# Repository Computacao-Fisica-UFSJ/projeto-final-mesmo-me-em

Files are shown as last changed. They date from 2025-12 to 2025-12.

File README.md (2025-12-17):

# Documentação Arduino - Gato Comedor de Moedas

DEPARTAMENTO DE CIÊNCIA DA COMPUTAÇÃO
BACHARELADO EM CIÊNCIA DA COMPUTAÇÃO

**Computação Física com Arduino**
Prof. Milene Barbosa Carvalho

**Autores:**

* Eduardo Gomes Martins
* Marina Rihs Matos Wang

---

## 1. Introdução

Este projeto consiste em criar um gato que engole moedas, com um contador que mostra o quanto de dinheiro o gato "engoliu". O gato foi modelado utilizando biscuit, o sistema para movimentação do gato e contagem das moedas foi feita com peças de arduino e uma régua impressa na impressora 3D para separar as moedas, e toda a estrutura foi construída com papelão.

A inspiração para a realização deste trabalho veio inicialmente do brinquedo "Stealing Coin Cat Bank" feito com um gatinho que puxa a a moeda para dentro da caixa sempre que a moeda é colocada em uma posição espeçífica. Por apresentar um mecanismo um pouco complexo para o arduino, nos inspiramos no brinquedo do "Cofre Devora Moedas", que, ao invés de puxar a moeda, ele simplesmente come, o que deixa o mecanismo mais simples.

---

## 2. Materiais

### 1. Arduino MEGA 2560

<div align="center">
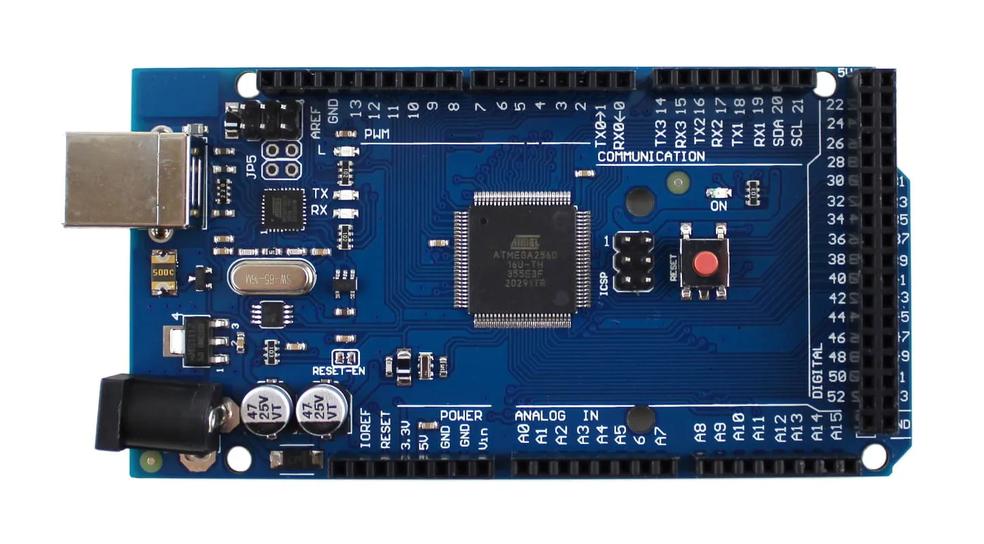
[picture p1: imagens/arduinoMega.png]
  
</div>

### 2. 2 x Breadboard - Full-Size

<div align="center">
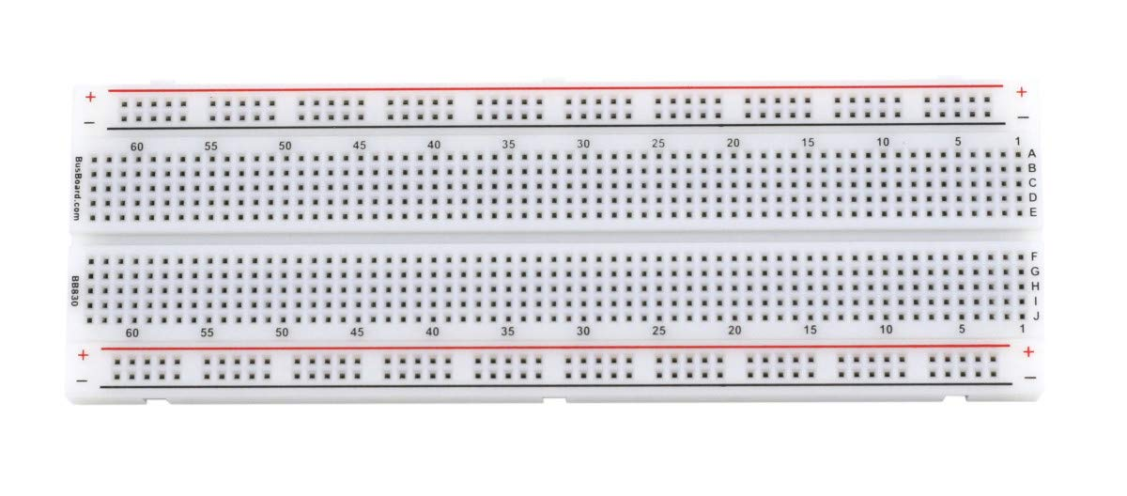
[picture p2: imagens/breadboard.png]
  
</div>

### 3. Jump Wires

<div align="center">
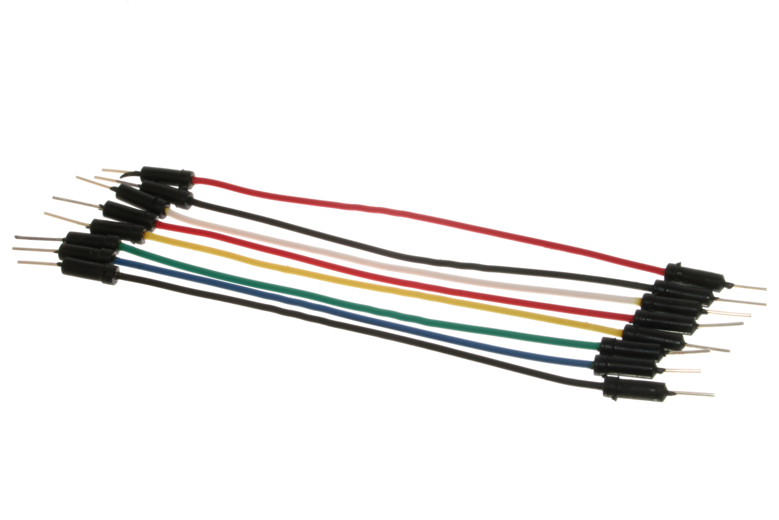
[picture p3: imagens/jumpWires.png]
  
</div>

### 4. Jump Wires Male to Female

<div align="center">
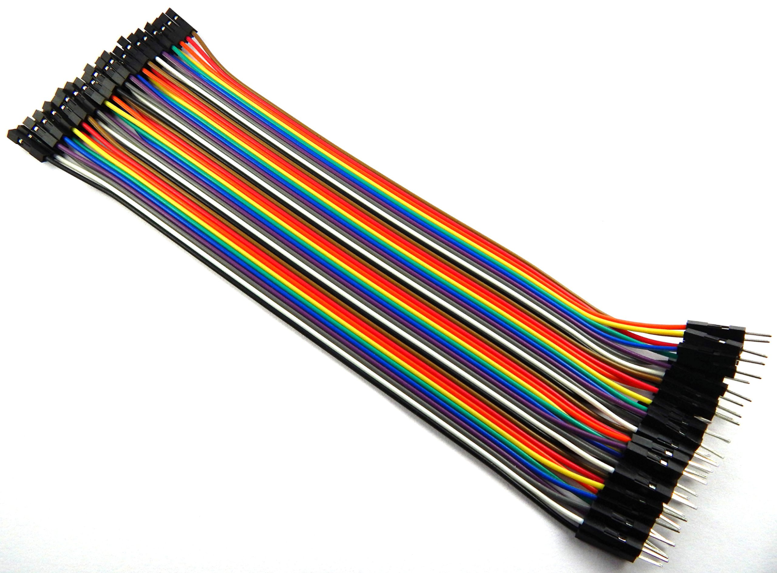
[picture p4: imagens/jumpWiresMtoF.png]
  
</div>

### 5. Jump Wires Female to Female

<div align="center">
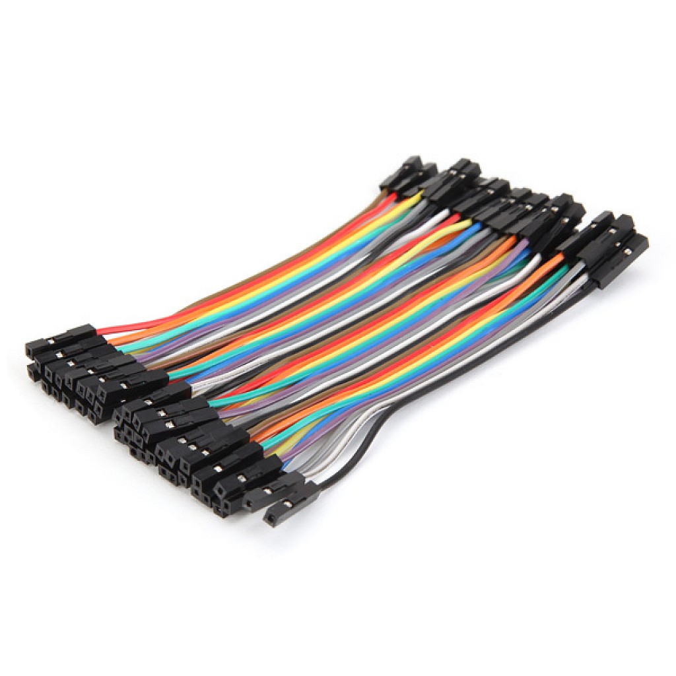
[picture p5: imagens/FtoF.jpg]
  
</div>

### 6. 7 x Sensor Infra Vermelho IR Emissor + Receptor

<div align="center">
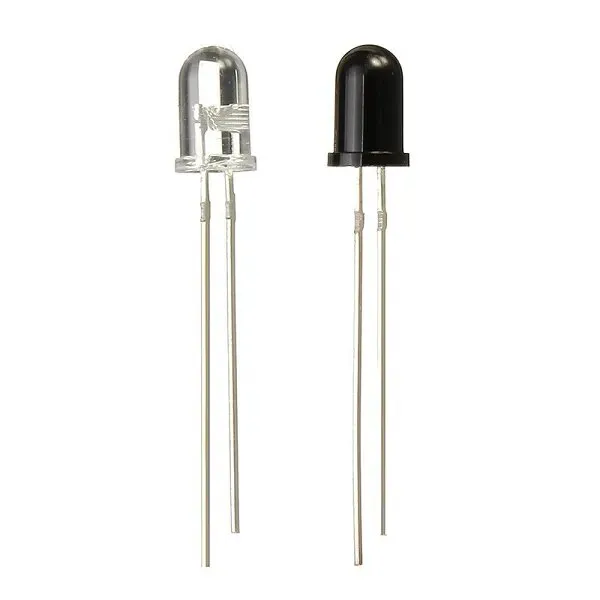
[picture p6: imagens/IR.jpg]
  
</div>

### 7. 7 x Resistor 10k ohm

<div align="center">
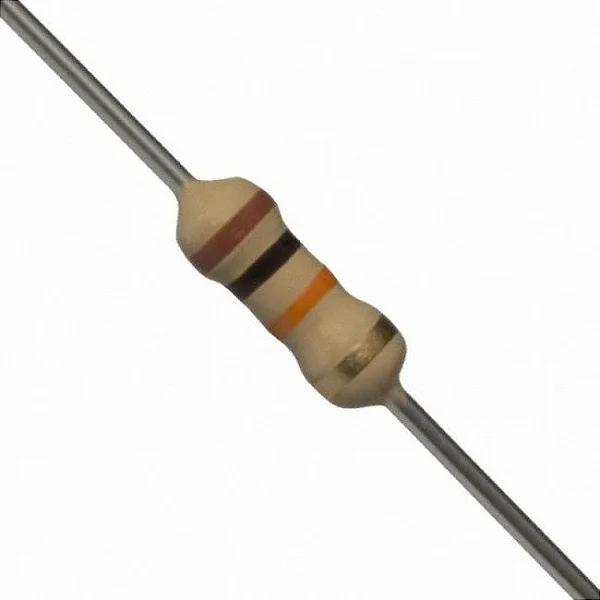
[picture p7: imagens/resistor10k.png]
  
</div>

### 8. 7 x Resistor 300 ohm

<div align="center">
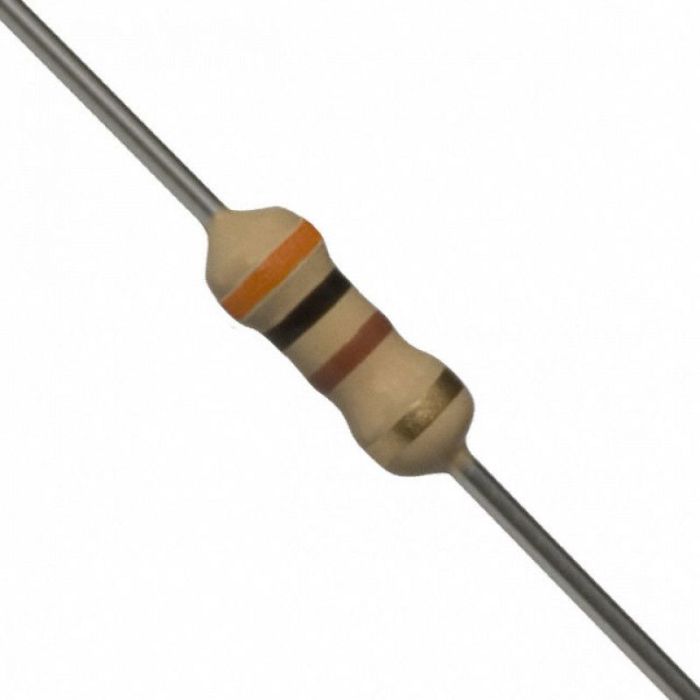
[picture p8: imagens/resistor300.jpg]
  
</div>

### 9. Limit Switch

<div align="center">
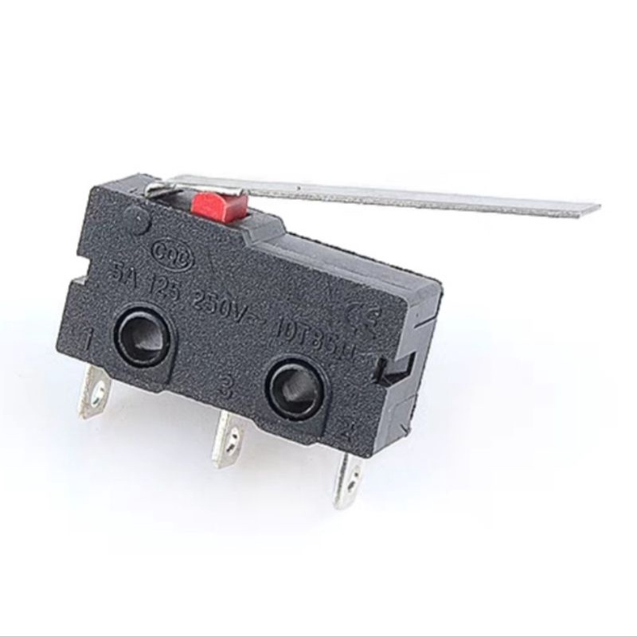
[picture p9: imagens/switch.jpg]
  
</div>

### 10. Grove-LCD RGB Backlight V2.0

<div align="center">
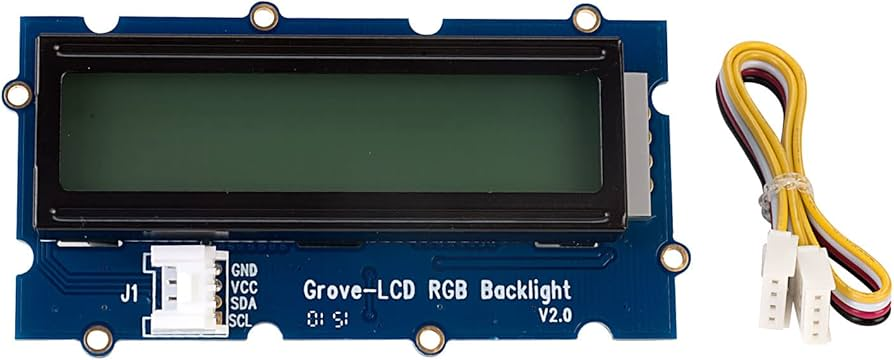
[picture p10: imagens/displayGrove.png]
  
</div>

---

## 3. Diagrama da Montagem (Fritzing)

<div align="center">
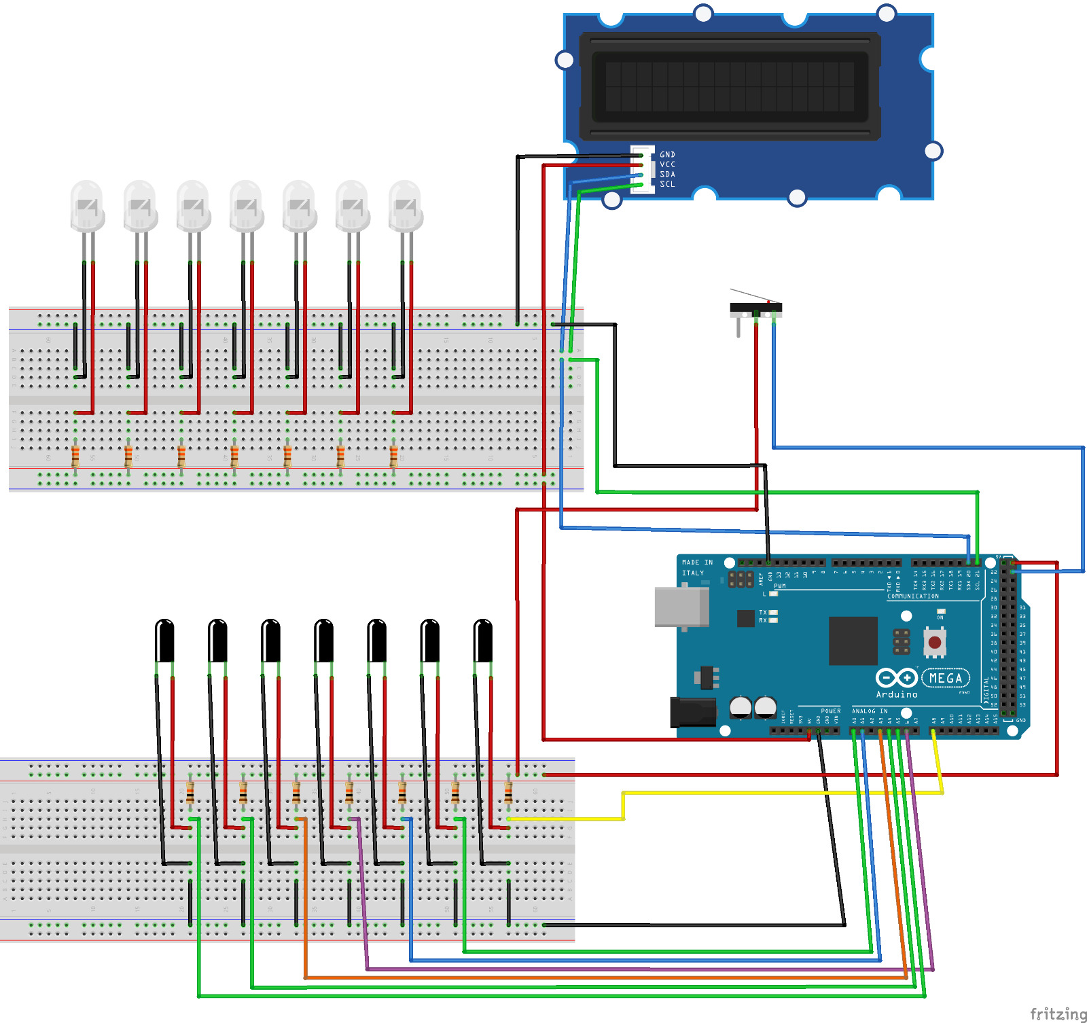
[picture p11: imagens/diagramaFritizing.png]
  
</div>

---

## 4. Explicação Textual do Diagrama

O circuito é dividido em três partes principais:

### 1. Switch
* O switch seria utilizado futuramente para ativar o mecanismo do gato, por  agora apenas libera uma mensagem.
* Ele é conectado no ground e ao pino 23, utilizando INPUT_PULLUP para fazer a leitura.

### 2. Sensores Infra Vermelho IR Emissor + Receptor
* Os sensores são utilizados para contabilizar as moedas, dependendo qual sensor teve seu valor modificado, identificamos qual o valor da moeda.
* Cada receptor está ligado a um pino de entrada analógica: A0, A1, A3, A4, A5, A6 e A8 sendo alimentado utilizando o resistor de 10k para limitar a corrente e evitar danos.
* Cada emissor está sendo alimentado utilizando o resistor de 330Ω para limitar a corrente e evitar danos.

### 3. Display LCD RGB
* Exibe o dinheiro total que passou pelo gato.
* Comunicação I2C pelos pinos 20 (SDA) e 21 (SCL).

---

## 5. Fotos/Vídeos do Projeto

* `Link do drive:` [https://drive.google.com/drive/folders/1Pybfmc_FEBHTFAq_Zw0lyVmJ8qzrmmvx](https://drive.google.com/drive/folders/1Pybfmc_FEBHTFAq_Zw0lyVmJ8qzrmmvx)

---

## 6. Problemas encontrados no Processo de Montagem

**a) Informações sobre componentes**

* Houve uma dificuldade para encontrar uma informações sobre como os sensores IR separados funcionavam no arduino e quais resistores são utilizados.
* Assim como os sensores IR, houve dificuldade em achar informações sobre o limit switch, em específico como funcionva sua alimentação de energia.

**b) Montagem do projeto**

* A régua que separa as moedas estava travando as moedas em pontos específicos, a solução foi ajeitar os buracos da régua com um pedaço de tecido para diminuir o diâmetro.
* Outro problema foi ajustar a inclinação da régua e o jeito com que a moeda cai sobre a régua.
* A mecânica do gato não funcionou como o esperado, ajustar o servo motor para movimentar a boca e os braços acabou ficando para a próxima atualização.
* Houve dificuldade em alinhar os infravermelhos em cada posição da régua, com um pouco de paciência, funcionou.

---

## 7. Referências

* Modelo 3D da régua separadora de moedas: [https://www.printables.com/model/53280-improved-auto-coin-sorter-v75-coin-roll-classic-ve/files](https://www.printables.com/model/53280-improved-auto-coin-sorter-v75-coin-roll-classic-ve/files)
* Datasheets dos componentes (LED, resistores, buzzer, botões, Arduino Uno).
* Documentação do LCD Grove RGB: [https://wiki.seeedstudio.com/Grove-LCD_RGB_Backlight/](https://wiki.seeedstudio.com/Grove-LCD_RGB_Backlight/)
* Documentação oficial do Arduino: [https://docs.arduino.cc/](https://docs.arduino.cc/)

---

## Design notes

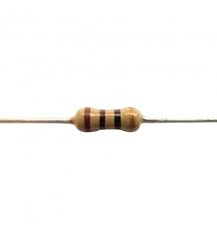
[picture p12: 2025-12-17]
imagens/resistor10.png

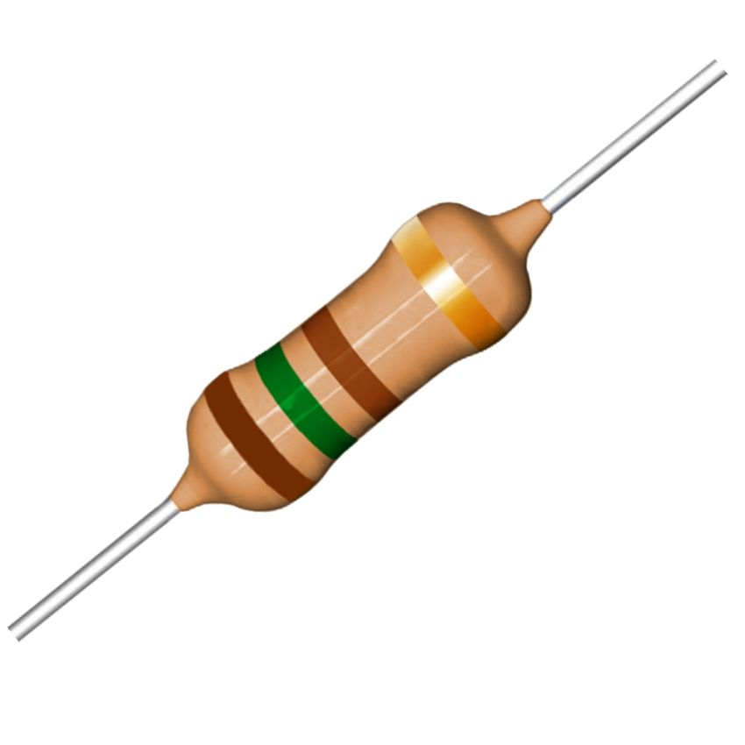
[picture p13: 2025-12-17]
imagens/resistor150.png

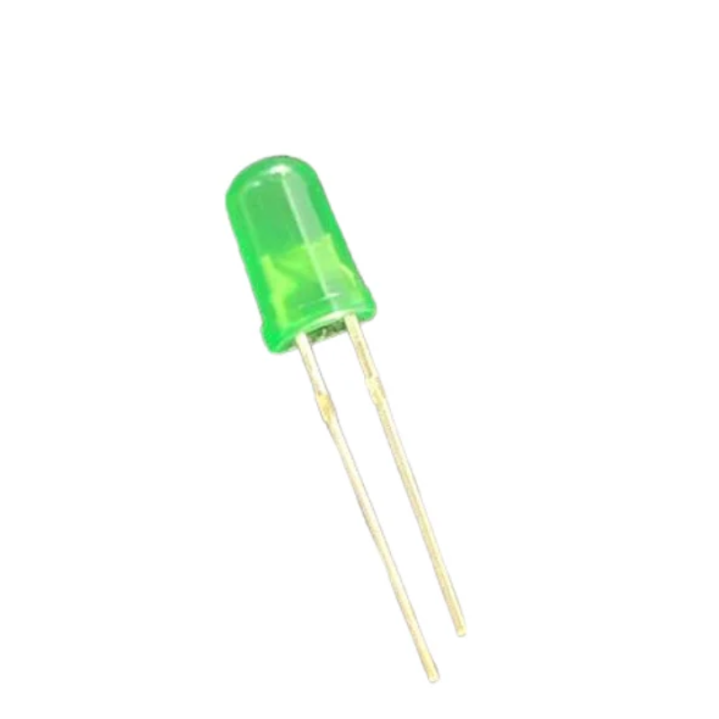
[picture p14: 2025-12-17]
imagens/ledVerde.png

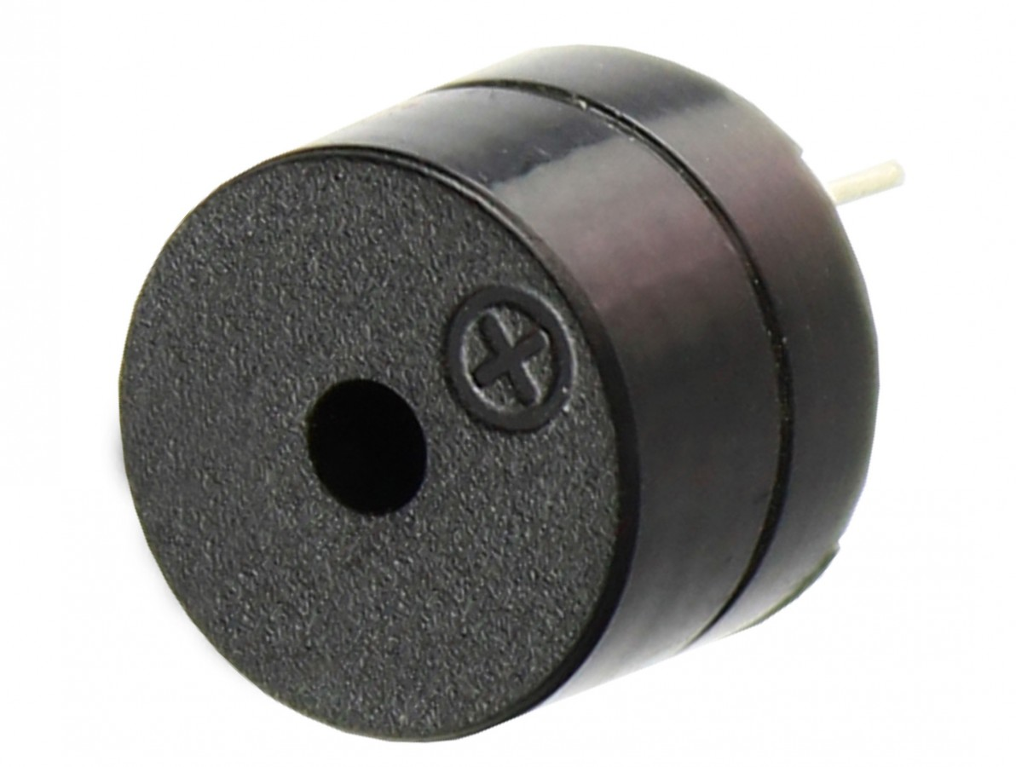
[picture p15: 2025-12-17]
imagens/buzzer.png

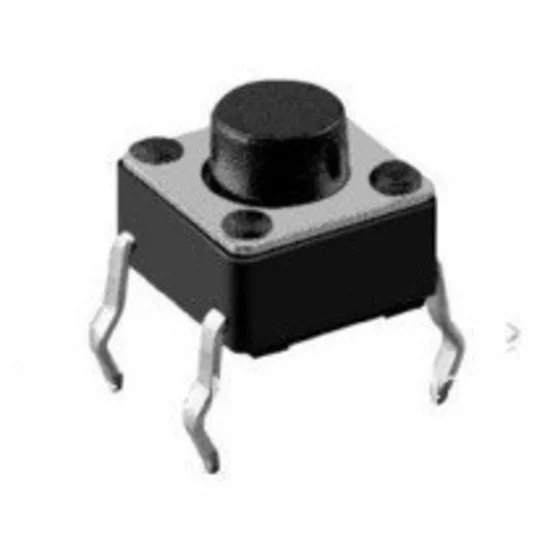
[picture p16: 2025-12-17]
imagens/pushButton.png

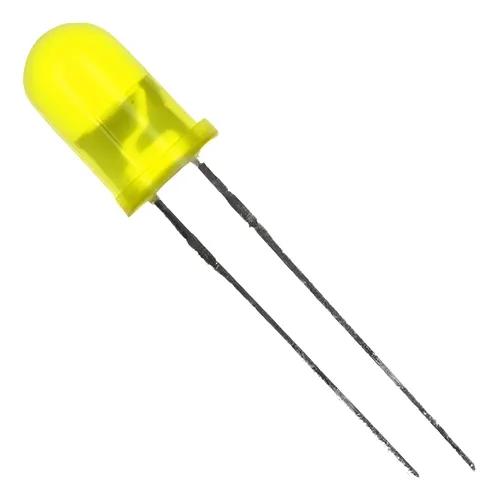
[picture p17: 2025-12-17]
imagens/ledAmarelo.png

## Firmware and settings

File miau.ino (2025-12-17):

#include "rgb_lcd.h"
//#include <Servo.h>
#include <EEPROM.h>

//pinos
#define PIN_SWITCH 23

//#define SERVO_PIN 5
#define IR_PIN_5v A0
#define IR_PIN_10 A1
#define IR_PIN_25v A3
#define IR_PIN_25 A4
#define IR_PIN_50 A6
#define IR_PIN_1 A5
#define IR_PIN_5 A8


//variaveis
double dinheiros = 0.00;
double ultimoValorLCD = -1;
int cinco = 0;
int dez = 0;
int vinteCinco = 0;
int cinquenta = 0;
int um = 0;
int irValue = 0;
boolean bocaFechada = false;
int contador = 0;

//debounce IR
bool IR5 = false;
bool IR10 = false;
bool IR25 = false;
bool IR50 = false;
bool IR1 = false;
bool IR25v = false;
bool IR5v = false;
int leitura5;
int leitura10;
int leitura25;
int leitura50;
int leitura1;
int leitura5v;
int leitura25v;

//lcd
rgb_lcd lcd;
int colorR = 255;
int colorG = 0;
int colorB = 0;

//Servo myservo;

void setup() {
  Serial.begin(9600);
  
  // Recupera valores guardados na memória
  //EEPROM.get(0, dinheiros);
  // EEPROM.get(8, cinco);
  // EEPROM.get(10, dez);
  // EEPROM.get(12, vinteCinco);
  // EEPROM.get(14, cinquenta);
  // EEPROM.get(16, um);

  // Seta os pinos
  pinMode(PIN_SWITCH, INPUT_PULLUP);
  pinMode(IR_PIN_5, INPUT);
  pinMode(IR_PIN_10, INPUT);
  pinMode(IR_PIN_25, INPUT);
  pinMode(IR_PIN_50, INPUT);
  pinMode(IR_PIN_1, INPUT);
  pinMode(IR_PIN_5v, INPUT);
  pinMode(IR_PIN_25v, INPUT);
  
  // Servo
//  /myservo.attach(SERVO_PIN);
  
  // Iniciar LCD
  lcd.begin(16, 4);
  lcd.setRGB(colorR, colorG, colorB); //cor
  lcd.setCursor(0, 0); // col x lin
  lcd.print("Dinheiros: ");
  lcd.setCursor(0, 1); // col x lin
  lcd.print("R$ ");
  lcd.print(dinheiros);
}

void loop() {
  calcularDinheiros();
  
  if(digitalRead(PIN_SWITCH) == LOW){
//    for (int pos = 90; pos >= 0; pos--) {
//      calcularDinheiros();
//      myservo.write(pos);
//      delay(15);
//    }
//    bocaFechada = true;
      Serial.println("Botao pressionado!!");
  }

  if(bocaFechada){
    contador++;
    delay(15);
  }

  if(contador == 200){
    for (int pos = 0; pos <= 90; pos++) {
      calcularDinheiros();
      myservo.write(pos);
      delay(15); 
    }
    bocaFechada = false;
    contador = 0;
  }

}

void atualizarMemoria(){
  EEPROM.put(0, dinheiros);
  // EEPROM.put(8, cinco);
  // EEPROM.put(10, dez);
  // EEPROM.put(12, vinteCinco);
  // EEPROM.put(14, cinquenta);
  // EEPROM.put(16, um);
}

void resetarMemoria(){
  dinheiros = 0;
  cinco = 0;
  dez = 0;
  vinteCinco = 0;
  cinquenta = 0;
  um = 0;

  EEPROM.put(0, dinheiros);
  // EEPROM.put(8, cinco);
  // EEPROM.put(10, dez);
  // EEPROM.put(12, vinteCinco);
  // EEPROM.put(14, cinquenta);
  // EEPROM.put(16, um);
}

void atualizarLCD() {
  if (dinheiros != ultimoValorLCD) {
    lcd.setCursor(0, 0);
    lcd.print("Dinheiros:     ");

    lcd.setCursor(0, 1);
    lcd.print("R$ ");
    lcd.print(dinheiros , 2);
    lcd.print("     ");

    ultimoValorLCD = dinheiros;
  }
}



void calcularDinheiros(){
  leitura5 = analogRead(IR_PIN_5);
  leitura10 = analogRead(IR_PIN_10);
  leitura25 = analogRead(IR_PIN_25);
  leitura50 = analogRead(IR_PIN_50);
  leitura1 = analogRead(IR_PIN_1);
  leitura5v = analogRead(IR_PIN_5v);
  leitura25v = analogRead(IR_PIN_25v);


  
  // Conta moedas
  if(leitura5 > 1015 && !IR5){
    dinheiros += 0.05;
    cinco++;
    IR5 = true;
    //atualizarMemoria();
  }

  if(leitura10 > 1015 && !IR10){
    dinheiros += 0.10;
    dez++;
    IR10 = true;
  }
  if(leitura25 > 1015 && !IR25){
    dinheiros += 0.25;
    vinteCinco++;
    IR25 = true;
  }
  if(leitura50 > 120 && !IR50){
    dinheiros += 0.50;
    cinquenta++;
    IR50 = true;
  }
  if(leitura1 > 1015 && !IR1){
    dinheiros += 1.00;
    um++;
    IR1 = true;
  }
  if(leitura5v > 1015 && !IR5v){
    dinheiros += 0.05;
    cinco++;
    IR5v = true;
  }
  if(leitura25v > 1015 && !IR25v){
    dinheiros += 0.25;
    vinteCinco++;
    IR25v = true;
  }
 
  // Debounce
  if(leitura5 < 1006){
    IR5 = false;
  }
  if(leitura10 < 1006){
    IR10 = false;
  }
  if(leitura25 < 1006){
    IR25 = false;
  }
  if(leitura50 < 50){
    IR50 = false;
  }
  if(leitura1 < 1006){
    IR1 = false;
  }
  if(leitura5v < 1006){
    IR5v = false;
  }
  if(leitura25v < 1006){
    IR25v = false;
  }

  atualizarLCD();

  
  //Serial.print("Dinheiro = ");
//  Serial.println(leitura5);
  

}
